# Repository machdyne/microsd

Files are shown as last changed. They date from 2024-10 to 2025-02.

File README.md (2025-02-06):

# High-Speed MicroSD Pmod&trade; compatible module

This is a 12-pin Pmod™ compatible module with a MicroSD slot and optional 3.3V<->1.8V level translation.

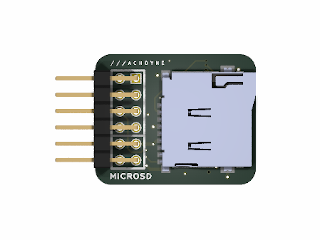
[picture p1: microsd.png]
MicroSD PMOD


This repo contains pinouts, schematics and PCB layouts.

Find more information on the [MicroSD product page](https://machdyne.com/product/microsd-pmod/).

## Pinout

| Pin | Signal|
| --- | ----- |
| 1 | SD\_SS |
| 2 | SD\_MOSI |
| 3 | SD\_MISO |
| 4 | SD\_SCK |
| 5 | GND |
| 6 | 3V3 |
| 7 | SD\_DAT1 |
| 8 | SD\_DAT2 |
| 9 | SD\_CD |
| 10 | SD\_VSEL18 |
| 11 | GND |
| 12 | 3V3 |

Note: 1.8V signals are used when SD\_VSEL18 is high, or 3.3V when low (default).

Note: When SD\_CD is asserted high for >100ms, power is shut off to the MicroSD card, allowing reset. All other signals should be held low during reset.

## Revisions

| Revision | Stackup | Notes |
| --- | --- | ----- |
| V0 | Aisler 4L | Initial prototype |

## License

The contents of this repo are released under the [Lone Dynamics Open License](LICENSE.md).

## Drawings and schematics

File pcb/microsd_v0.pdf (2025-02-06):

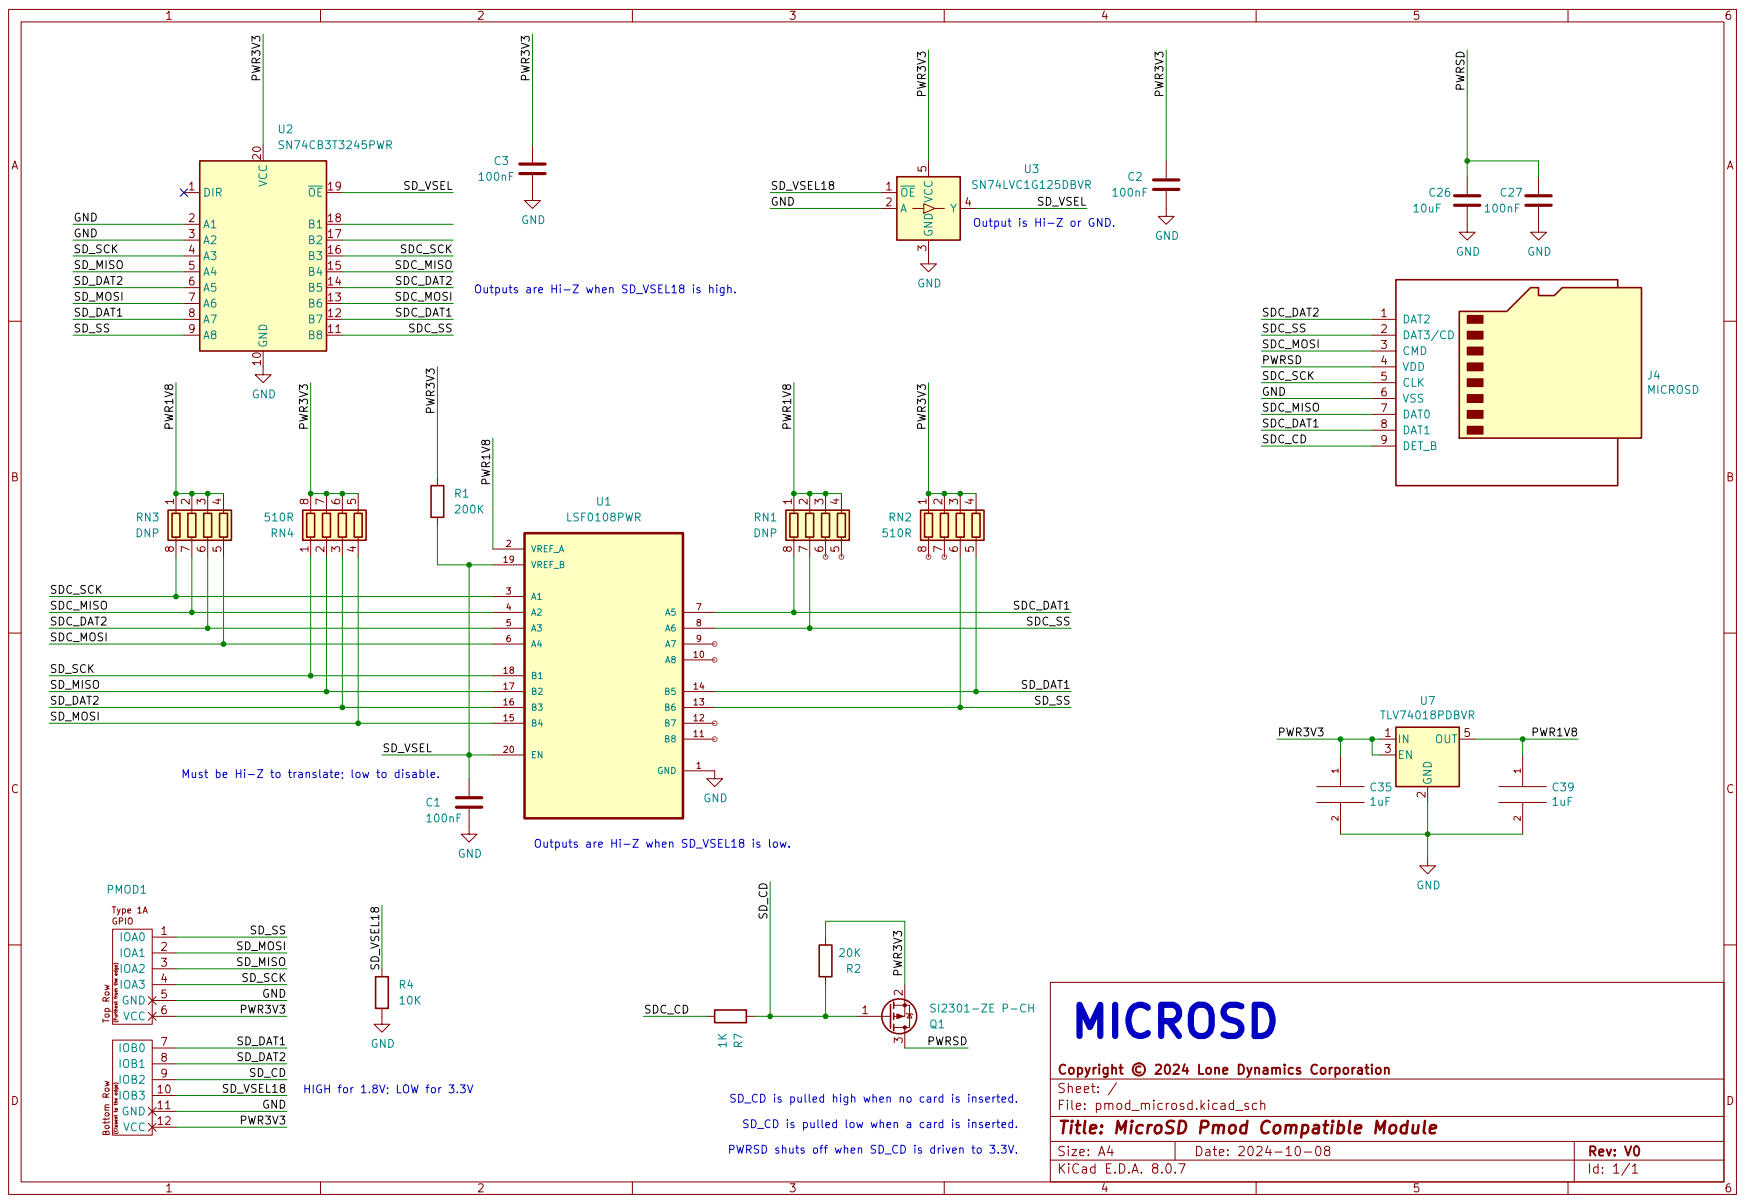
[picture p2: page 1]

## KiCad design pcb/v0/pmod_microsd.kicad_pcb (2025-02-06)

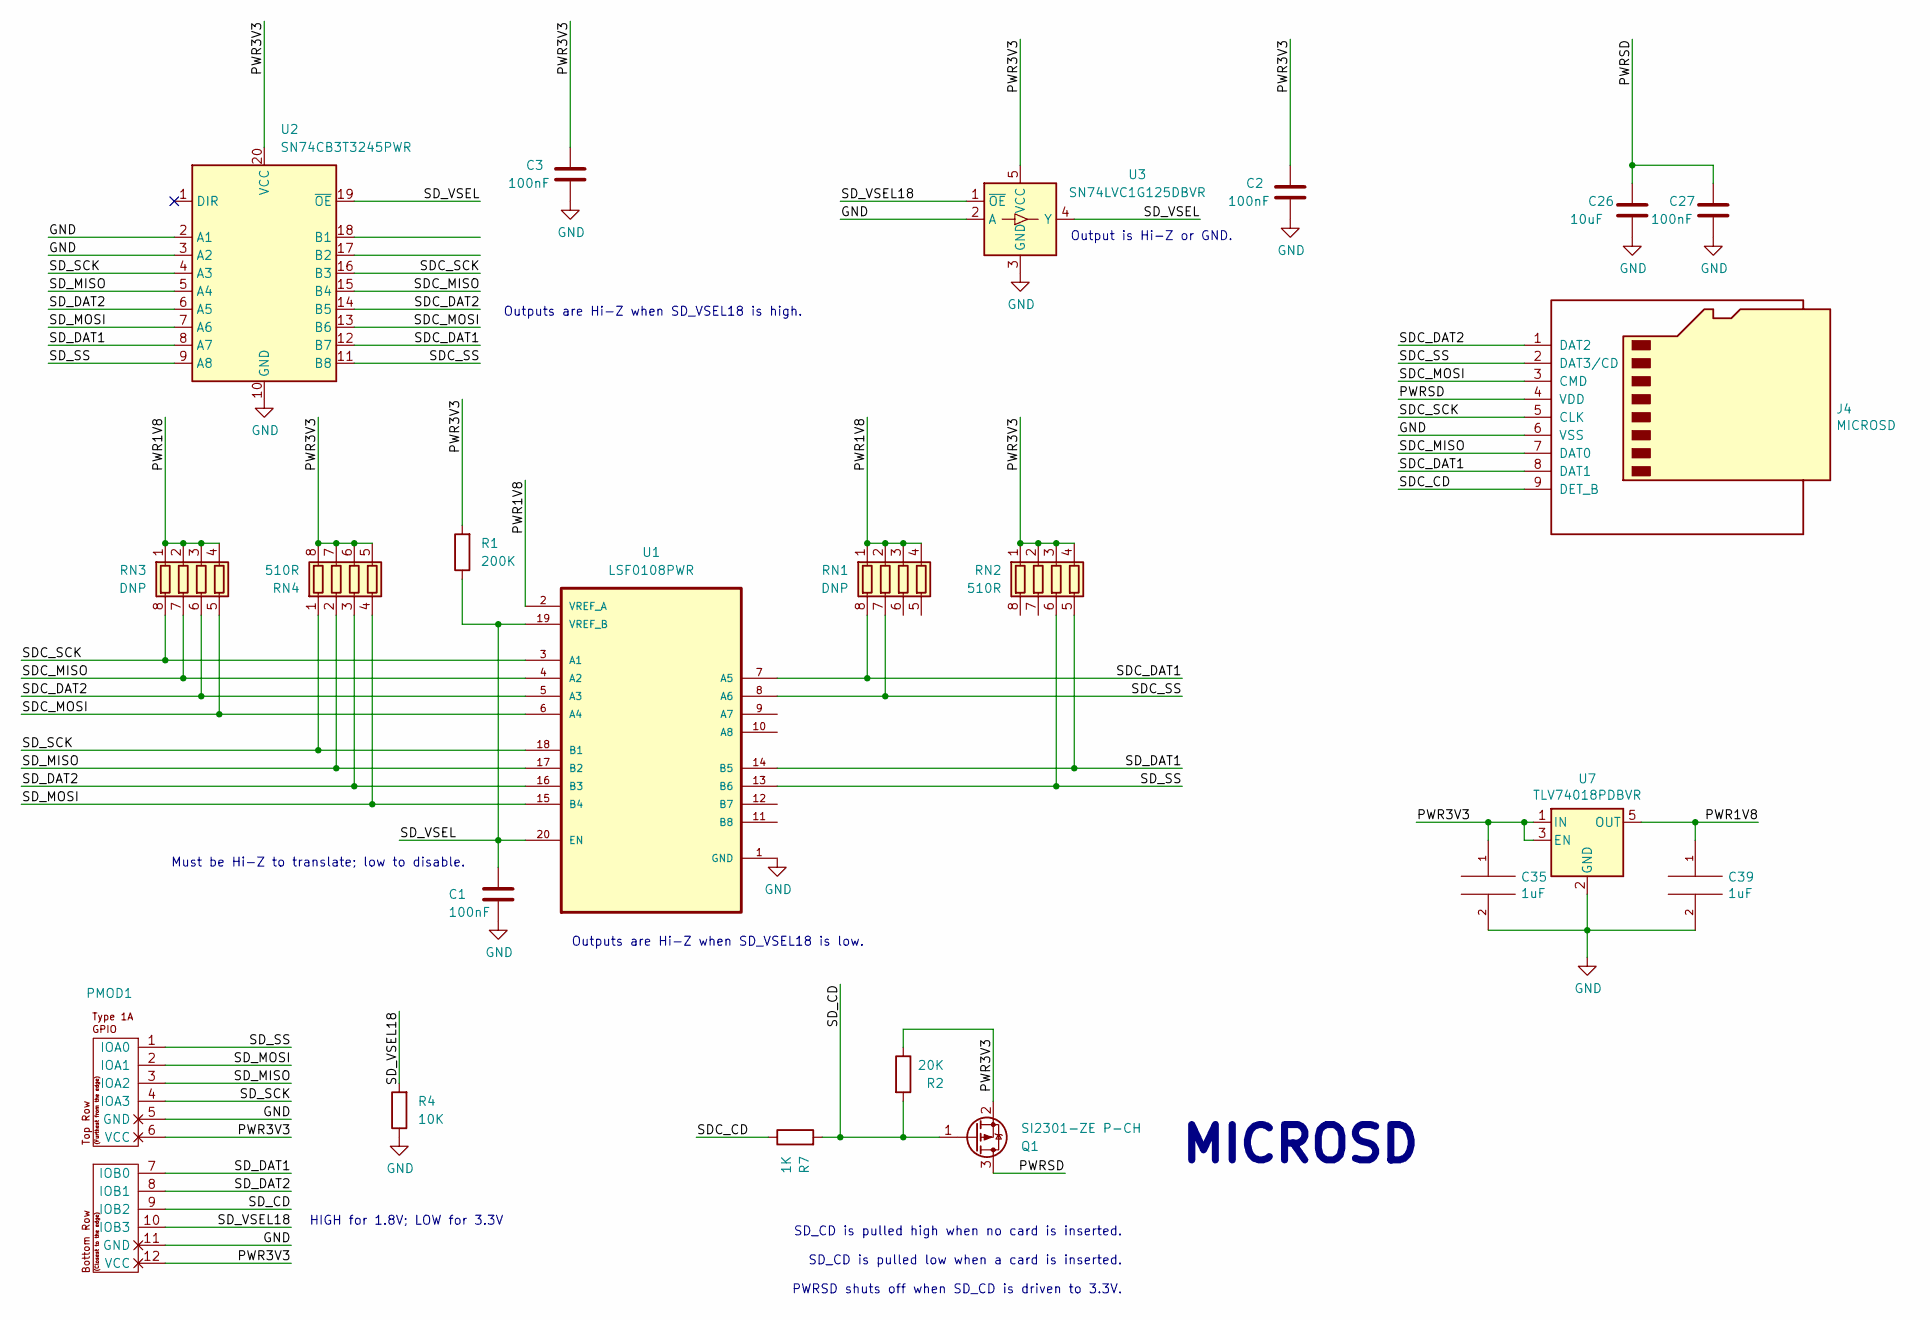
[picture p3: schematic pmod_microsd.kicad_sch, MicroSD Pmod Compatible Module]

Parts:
C1, C2, C3, C27: 100nF; C_0402_1005Metric
C26: 10uF; C_0402_1005Metric
C35, C39: 1uF; C_0402_1005Metric
J4: MICROSD; SDCARD
PMOD1: PMOD-Device-x2-Type-1A-GPIO; pmod_pin_array_6x2
Q1: SI2301-ZE P-CH; SOT-23
R1: 200K; R_0402_1005Metric
R2: 20K; R_0402_1005Metric
R4: 10K; R_0402_1005Metric
R7: 1K; R_0402_1005Metric
RN1, RN3: DNP; R_Array_Convex_4x0402
RN2, RN4: 510R; R_Array_Convex_4x0402
U1: LSF0108PWR; TSSOP-20_4.4x6.5mm_P0.65mm
U2: SN74CB3T3245PWR; TSSOP-20_4.4x6.5mm_P0.65mm
U3: SN74LVC1G125DBVR; SOT-23-5
U7: TLV74018PDBVR; SOT-23-5

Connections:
/PWR1V8: C39.1, RN1.1 (R1.1), RN1.2 (R2.1), RN1.3 (R3.1), RN1.4 (R4.1), RN3.1 (R1.1), RN3.2 (R2.1), RN3.3 (R3.1), RN3.4 (R4.1), U1.2 (VREF_A), U7.5 (OUT)
/PWR3V3: C2.1, C3.1, C35.1, PMOD1.6 (VCC), PMOD1.12 (VCC), Q1.2 (S), R1.2, R2.1, RN2.1 (R1.1), RN2.2 (R2.1), RN2.3 (R3.1), RN2.4 (R4.1), RN4.5 (R4.2), RN4.6 (R3.2), RN4.7 (R2.2), RN4.8 (R1.2), U2.20 (VCC), U3.5 (VCC), U7.1 (IN), U7.3 (EN)
/PWRSD: C26.1, C27.1, J4.4 (VDD), Q1.3 (D)
/SDC_CD: J4.9 (DET_B), R7.1
/SDC_DAT1: J4.8 (DAT1), RN1.8 (R1.2), U1.7 (A5), U2.12 (B7)
/SDC_DAT2: J4.1 (DAT2), RN3.6 (R3.2), U1.5 (A3), U2.14 (B5)
/SDC_MISO: J4.7 (DAT0), RN3.7 (R2.2), U1.4 (A2), U2.15 (B4)
/SDC_MOSI: J4.3 (CMD), RN3.5 (R4.2), U1.6 (A4), U2.13 (B6)
/SDC_SCK: J4.5 (CLK), RN3.8 (R1.2), U1.3 (A1), U2.16 (B3)
/SDC_SS: J4.2 (DAT3/CD), RN1.7 (R2.2), U1.8 (A6), U2.11 (B8)
/SD_CD: PMOD1.9 (IOB2), Q1.1 (G), R2.2, R7.2
/SD_DAT1: PMOD1.7 (IOB0), RN2.5 (R4.2), U1.14 (B5), U2.8 (A7)
/SD_DAT2: PMOD1.8 (IOB1), RN4.3 (R3.1), U1.16 (B3), U2.6 (A5)
/SD_MISO: PMOD1.3 (IOA2), RN4.2 (R2.1), U1.17 (B2), U2.5 (A4)
/SD_MOSI: PMOD1.2 (IOA1), RN4.4 (R4.1), U1.15 (B4), U2.7 (A6)
/SD_SCK: PMOD1.4 (IOA3), RN4.1 (R1.1), U1.18 (B1), U2.4 (A3)
/SD_SS: PMOD1.1 (IOA0), RN2.6 (R3.2), U1.13 (B6), U2.9 (A8)
/SD_VSEL: C1.1, R1.1, U1.19 (VREF_B), U1.20 (EN), U2.19 (~OE), U3.4 (Y)
/SD_VSEL18: PMOD1.10 (IOB3), R4.2, U3.1 (~OE)
GND: C1.2, C2.2, C3.2, C26.2, C27.2, C35.2, C39.2, J4.6 (VSS), PMOD1.5 (GND), PMOD1.11 (GND), R4.1, U1.1 (GND), U2.2 (A1), U2.3 (A2), U2.10 (GND), U3.2 (A), U3.3 (GND), U7.2 (GND)

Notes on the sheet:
SD_CD is pulled high when no card is inserted. SD_CD is pulled low when a card is inserted. PWRSD shuts off when SD_CD is driven to 3.3V.
Outputs are Hi-Z when SD_VSEL18 is high.
Must be Hi-Z to translate; low to disable.
Outputs are Hi-Z when SD_VSEL18 is low.
Output is Hi-Z or GND.
MICROSD
HIGH for 1.8V; LOW for 3.3V

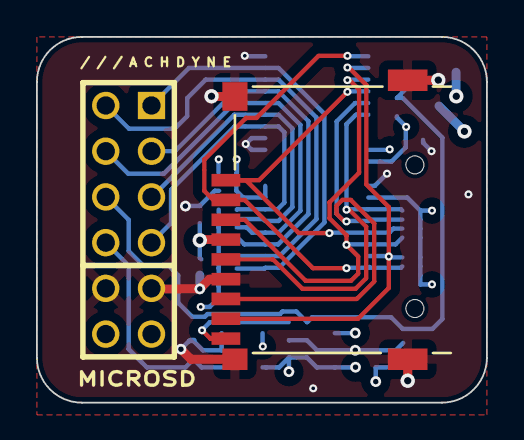
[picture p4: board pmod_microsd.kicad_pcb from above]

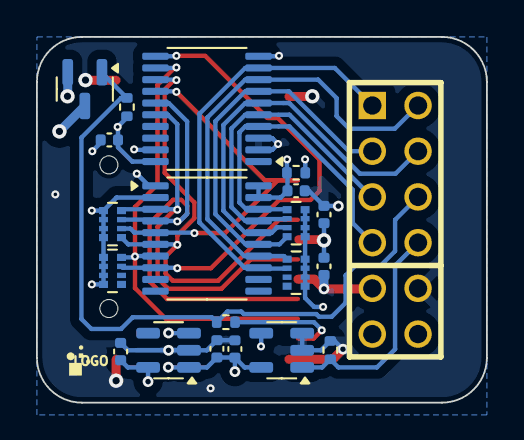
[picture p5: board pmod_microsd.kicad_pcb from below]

Board: 4 copper layers, 25.0 x 20.3 mm, 22 parts (20 on the bottom side), 20 nets.

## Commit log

2024-10-12 add hardware reset
    [pmod_microsd.kicad_pcb, pmod_microsd.kicad_sch]
2024-10-23 update values
    [pmod_microsd.kicad_pcb, pmod_microsd.kicad_sch]
2025-02-06 update readme & schematics
    [pmod_microsd.kicad_pcb, pmod_microsd.kicad_sch]

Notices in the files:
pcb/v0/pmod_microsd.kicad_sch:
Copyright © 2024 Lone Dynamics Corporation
